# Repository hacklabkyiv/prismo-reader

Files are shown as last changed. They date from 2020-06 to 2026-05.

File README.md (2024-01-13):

# PRISMO readers
# (WIP)

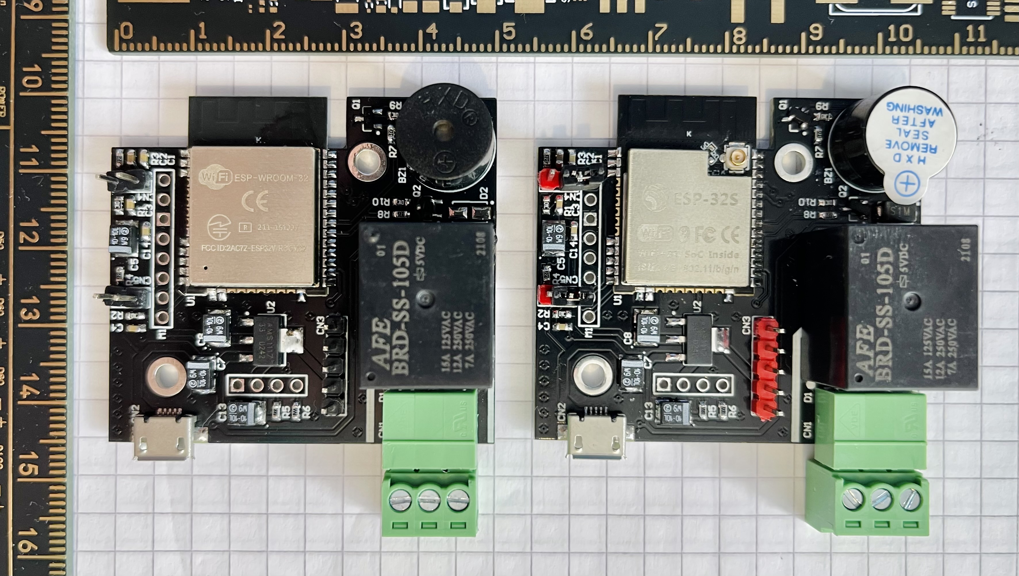
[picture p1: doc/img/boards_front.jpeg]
Boards


[Protocol description](./doc/protocol.md)

## Flashing instructions

Before any development mode interactions with the board it needs to be connected to a computer.
The interface intended for flashing and debugging is UART. Please connect your USB-UART adapter to the pins on the board as shown on the image below:

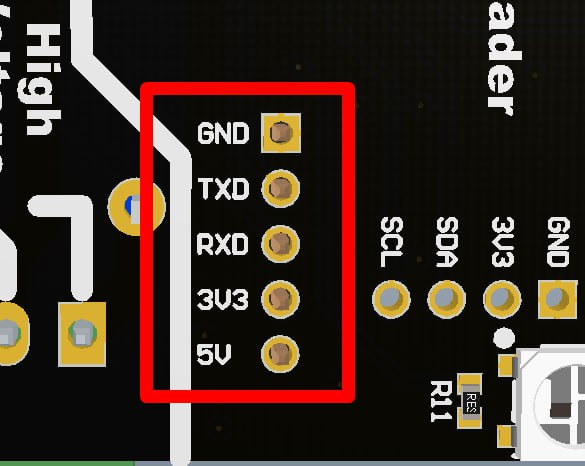
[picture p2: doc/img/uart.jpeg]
uart

```
READER  USB-UART
5V  ->  5V
GND ->  GND
RX  ->  TX
TX  ->  RX
optional
3V3 ->  3V3
```

First of all the information about Micropython and it's installation can be found on their official page: [https://micropython.org/download/esp32/](https://micropython.org/download/esp32/)

Depending on your prefered OS the USB-UART can be named differently.
For example:
 - MacOS `/dev/tty.usbserial-1220`
 - Ubuntu `/dev//dev/ttyUSB0`
 - Windows `COM1`

To enter to the flashing mode the board should start with BOOT0 pin pulled to GND.
In order to achieve that short and hold BOOT pins, then short and release ENABLE pins and then release BOOT pins.

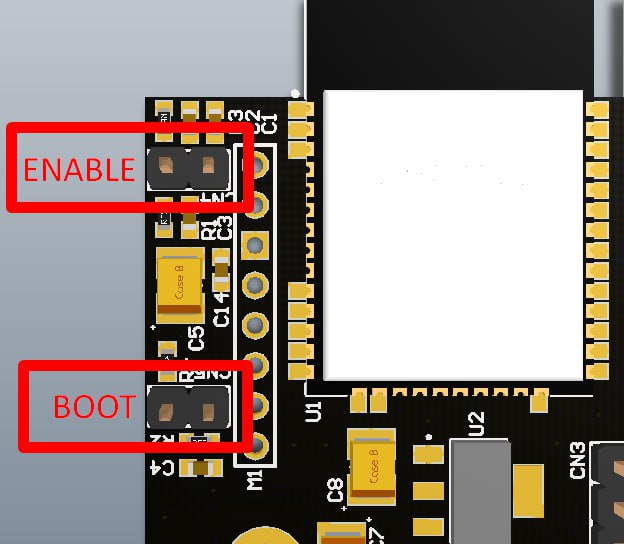
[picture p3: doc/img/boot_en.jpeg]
Boot


The commands also available below:
```sh
esptool.py --chip esp32 --port /dev/tty.usbserial-1220 erase_flash
```

```sh
esptool.py --chip esp32 --port /dev/tty.usbserial-1220 --baud 460800 write_flash -z 0x1000 esp32-20230426-v1.20.0.bin
```

To put source code files on board (ampy)[https://pypi.org/project/adafruit-ampy/] tool is needed.
Put all files from `src` folder to the board one by one.
> It is better for the main.py to be the last one.
>
> main.py starts processes which may affect further access to the board by `ampy` tool
> If that has happened - please enter to the REPL (`picocom` is a nice tool for that) mode and remove `main.py` manually.
> Use this prompt: `import os; os.remove('main.py')`. Don't forget to put `main.py` back in order to be back to normal operation.

```sh
ampy -p /dev/tty.usbserial-11210 -b115200 -d4 put boot.py
ampy -p /dev/tty.usbserial-11210 -b115200 -d4 put PN532.py
ampy -p /dev/tty.usbserial-11210 -b115200 -d4 put config.py
ampy -p /dev/tty.usbserial-11210 -b115200 -d4 put main.py
```
-----------
### HW test

After flashing your device, you can test your hardware. To do this, uncomment `HW_TEST` in `settings.h` file and flash this firmware. In serial monitor, with key is near the RFID frame (baudrate 9600) you should get something like this:

```
------ HW TEST STARTED --------
17:38:34.011 -> ------ HW TEST STARTED --------
17:38:37.001 -> 33384541313932323930304532333845413139323239303045323338454131393232393030453233384541313932323930304532333845413139323239303045323338454131393232393030453233384541
17:38:40.620 -> ------ HW TEST STARTED --------
17:38:43.608 -> ------ HW TEST STARTED --------

```

### Connection test with test server

Comment back `HW_TEST` in `settings.h` and specify network settings there.

```
STASSID	- name of your wifi network
STAPSK 	- password to your wifi network
HOST 	- IP address to your test server.
PORT	- Unique port of your reader
```

In `test_server.py` choose right `MY_IP` - IP of machine where `test_server.py` running and `READER_PORT`.

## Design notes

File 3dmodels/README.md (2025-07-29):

# STL and F3d models for printing the shells for indoor and outdoor use

# for indoor use

***internal_reader_shell_v3*** - main model for indoor euipment readers, can be printed from any plastic  
***logout_button*** - button extension small part  
***transparent_insert*** - installed inside the main model, printed from any kind of transparent filament  
***reader_pcb_spacer*** - 14mm spacers installed between the reader pcb and pn532 rfid scanner board  

***reader_internal_for_plasterboard*** - special model for the door reader to be installed inside a wall behind a 10mm plasterboard so the keys are scanned through the wall  

# for outdoor use 

***outside_sensor_holder_cnc*** - a piece for installing pn532 board. designed to be filled with epoxy and used outdoors. better to be milled from non-metals so they do not interfere with the rfid scanning  
***outside_sensor_holder_cnc_insert*** - 3d printed piece to better hold the pn532 inside the casing  
***outside_sensor_holder_print*** - 3d printed part for pn532 installation. designed to be filled with epoxy. better print from UV-resistant filaments such as ASA or PC  
***outside_sensor_holder_print_screw_plug*** - 3d printed plugs to cover the screws attaching the outdoor part to what it is mounted on  

***sensor_outside_reader_inside_horizontal*** - a box to hold the reader pcb to be mounted inside the room and connected to pn532 via wires. horizontal orientation to be mounted on the door close to the lock mechanism  
***sensor_outside_reader_inside_vertical*** - same but vertical orientation. better suited to be mounted on narrow door frames  

# editable 3d models 

three *.f3d Fusion 360 files that contain all mentioned models for modifications

Have fun!

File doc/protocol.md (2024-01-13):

Communication protocol

{
    "type": "request",
    "id": "BigMill",
    "key": "123534"
}

"type" field can be:
 - "request": ask from reader to server
 - "response": response from server
 - "heartbeat": keepalive heatbeat from reader to server.

"id": identifier of device. It is name of reader, which is usually is the same as the name of machine it is installed, or "server".

{
    "type": "request",
    "operation": "unlock",
    "id": "BigMill",
    "key": "123534"
}

{
    "type": "response",
    "result": "grant"
}

'result' variants
    'grant'
    'deny'
    'usernotfound'

{
    "type": "heartbeat",
    "id": "BigMill"
}

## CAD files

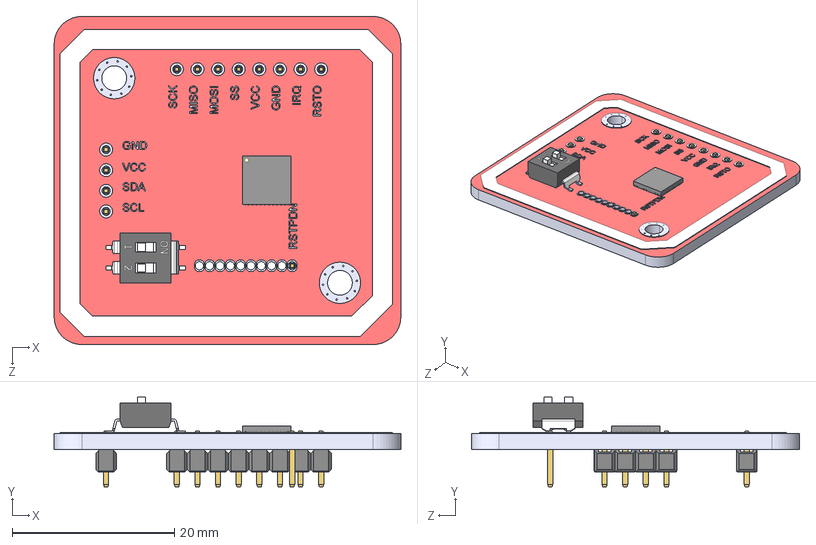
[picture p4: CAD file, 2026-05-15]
hw/rev.3.0/misc/PN532_NFC_Assembly.STEP
42.7 x 11.0 x 40.4 mm
NFC_MODULE_1
Pin Stand 2.54mm_1 x 12
QFN40 (6x6)_1
Switch_2_1
pin_my_1 x 13

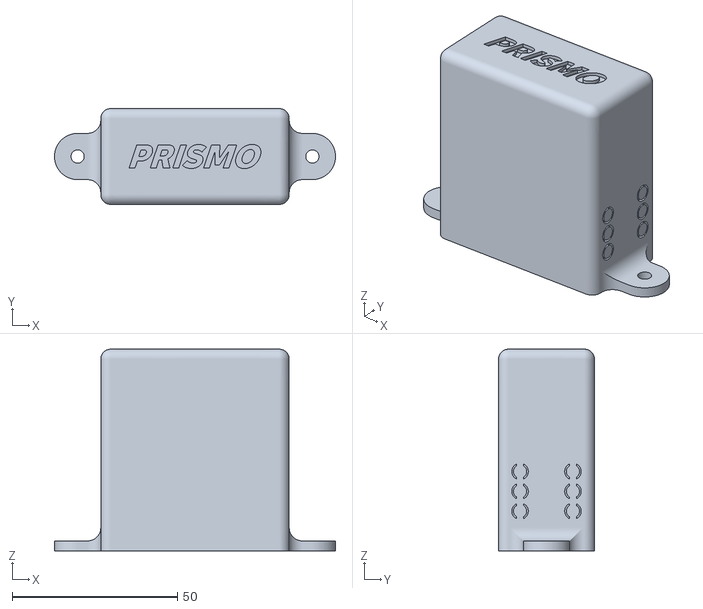
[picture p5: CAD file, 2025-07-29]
3dmodels/scanner_outside_reader_inside_vertical.stl
85.0 x 29.0 x 61.0

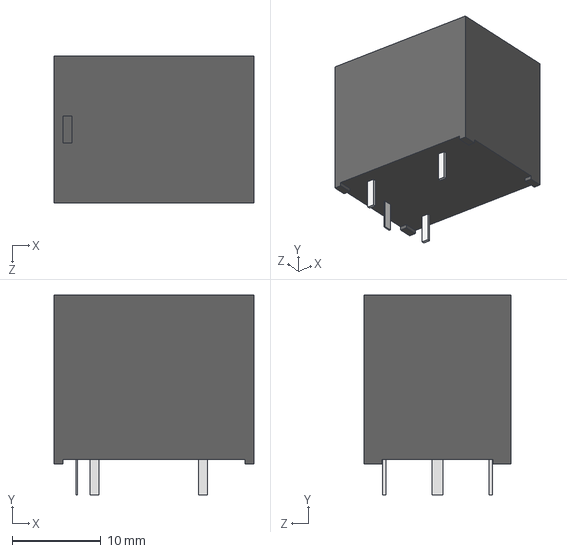
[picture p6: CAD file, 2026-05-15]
hw/rev.3.0/misc/G5LE_1A4.step
22.5 x 22.5 x 16.5 mm

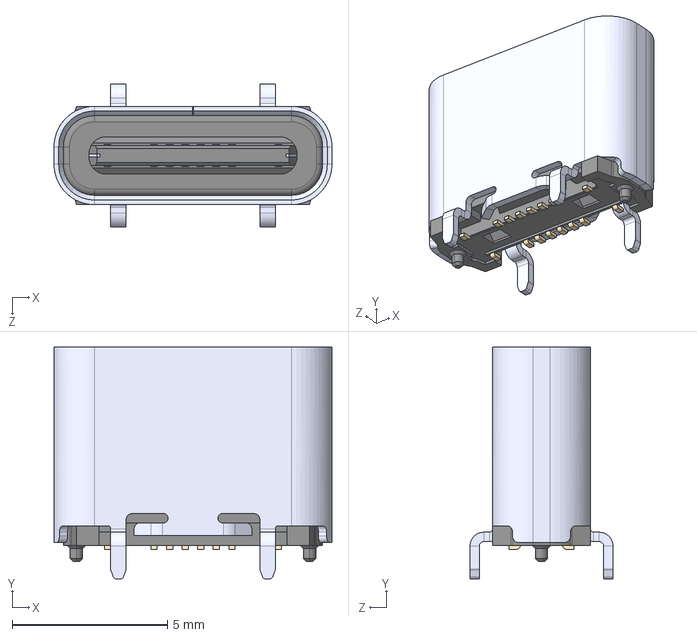
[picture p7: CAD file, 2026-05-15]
hw/rev.3.0/usb_connector/USB4120-03-C_REVA.step
8.94 x 7.45 x 4.60 mm

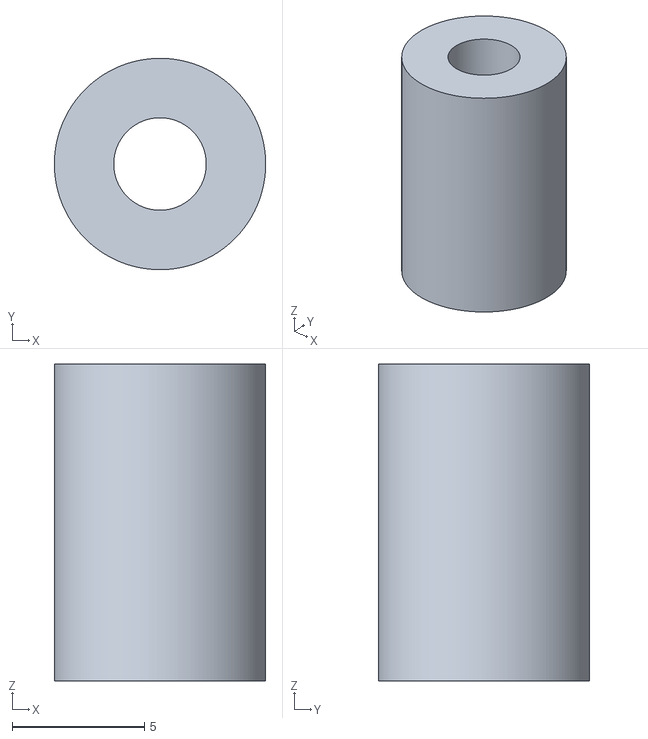
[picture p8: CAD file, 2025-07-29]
3dmodels/reader_pcb_spacer.stl
8.00 x 8.00 x 12.0

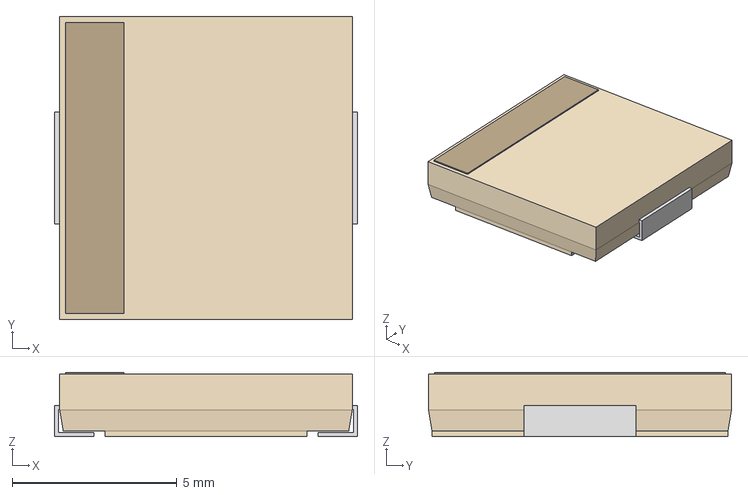
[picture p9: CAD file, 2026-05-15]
hw/rev.3.0/misc/PKMCS0909E4000-R1_MUR.step
9.19 x 9.19 x 1.96 mm

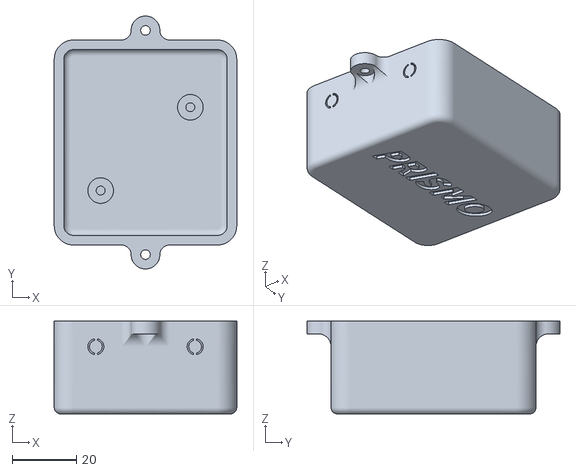
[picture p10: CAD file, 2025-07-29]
3dmodels/scanner_outside_reader_inside_horizontal.stl
57.0 x 79.0 x 29.0

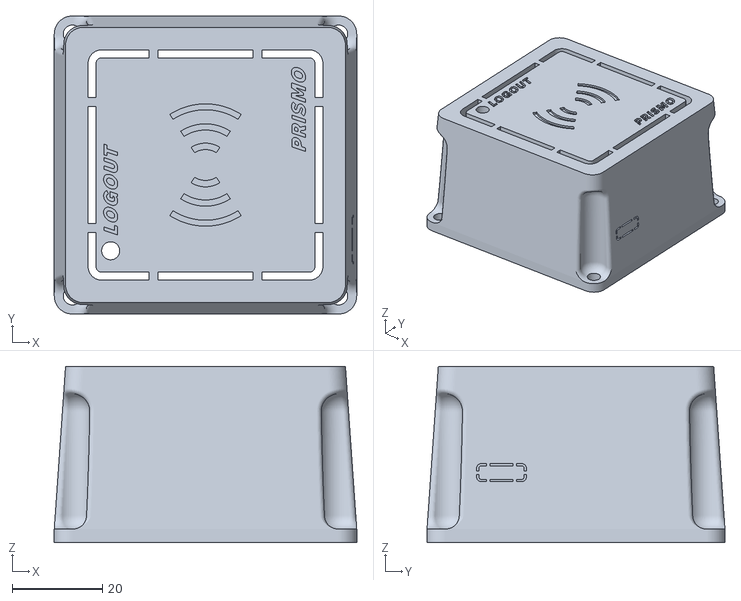
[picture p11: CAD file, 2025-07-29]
3dmodels/internal_reader_shell_v3.stl
67.0 x 66.0 x 39.0

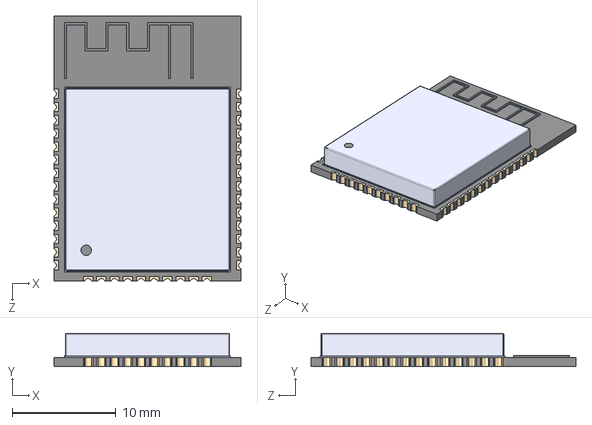
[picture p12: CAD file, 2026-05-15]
hw/rev.3.0/misc/ESP32-WROOM-32.step
18.0 x 3.20 x 25.5 mm

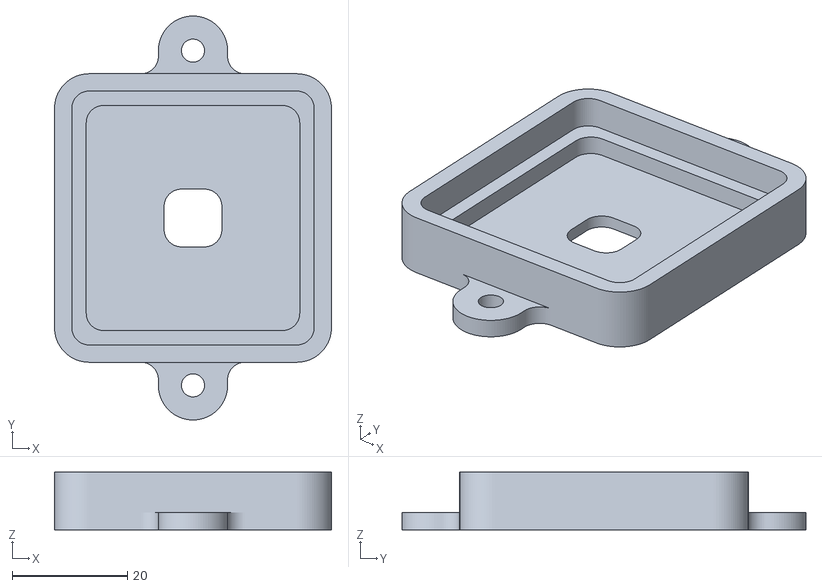
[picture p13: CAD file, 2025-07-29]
3dmodels/outside_sensor_holder_cnc.stl
48.0 x 70.0 x 10.0

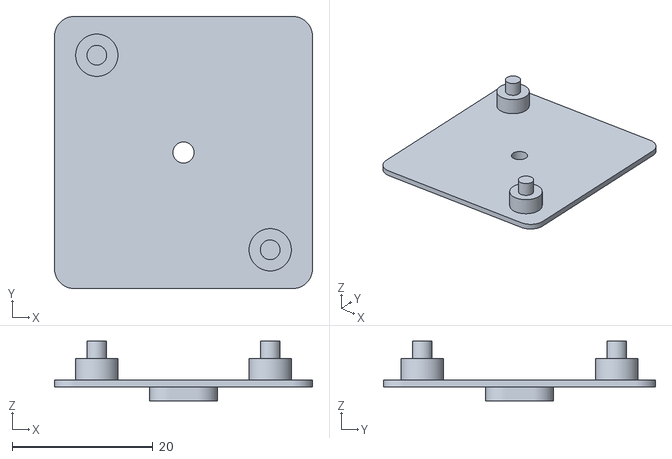
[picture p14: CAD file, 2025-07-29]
3dmodels/outside_sensor_holder_cnc_insert.stl
36.6 x 38.6 x 8.50

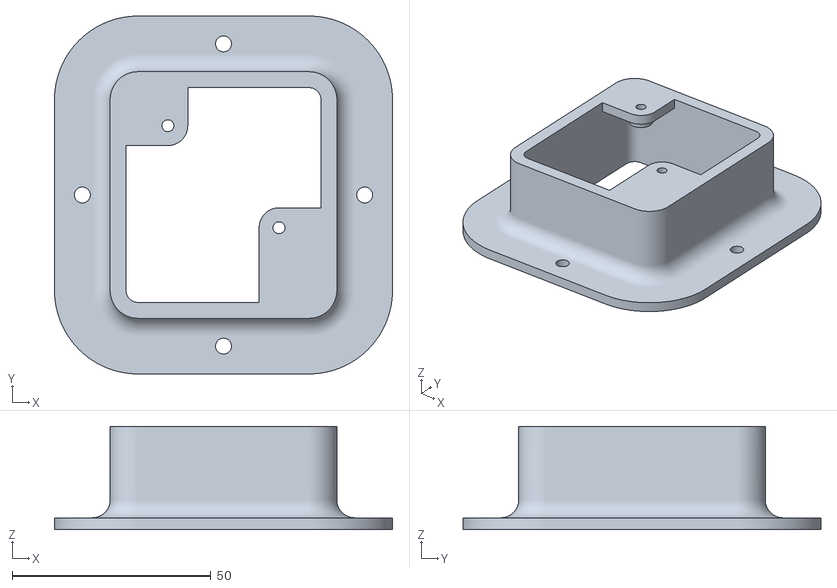
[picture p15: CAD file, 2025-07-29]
3dmodels/Reader_internal_for_plasterboard.stl
85.0 x 90.0 x 26.0

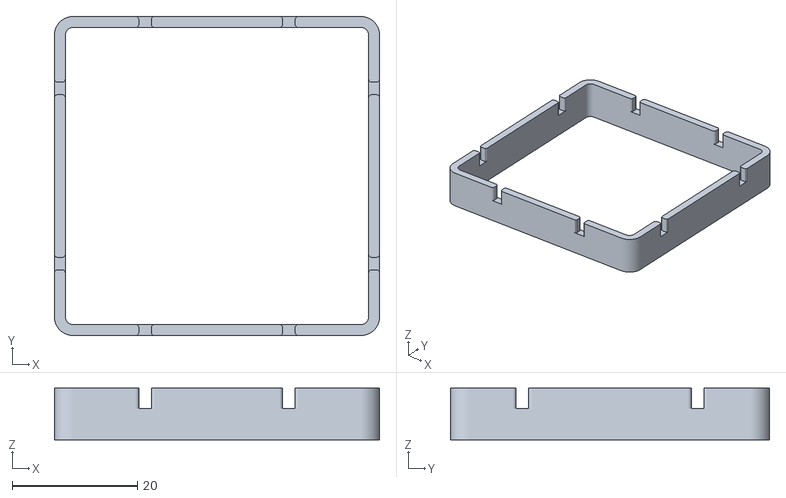
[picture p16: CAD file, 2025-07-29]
3dmodels/transparent_insert.stl
52.0 x 51.0 x 8.25

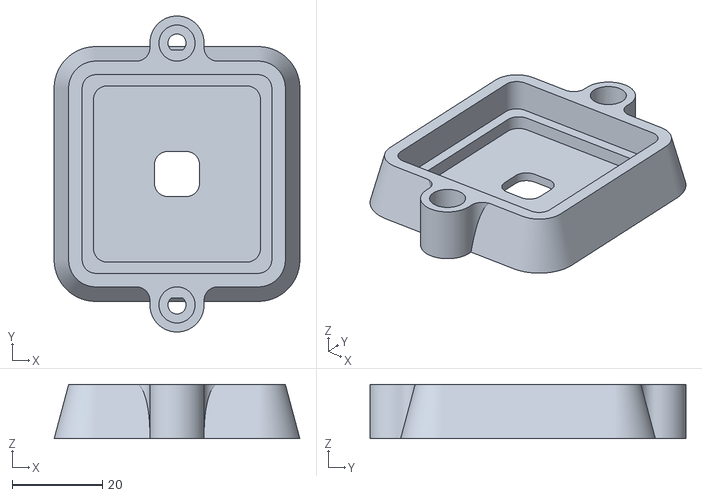
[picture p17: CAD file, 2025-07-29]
3dmodels/outside_sensor_holder_print.stl
54.4 x 70.0 x 12.0

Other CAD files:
3dmodels/logout_button.stl
3dmodels/outside_sensor_holder_print_screw_plug.stl
3dmodels/Reader_internal_plasterboard.f3d
3dmodels/Reader_shell_v3.f3d
3dmodels/reader_scanner_case_v3.f3d

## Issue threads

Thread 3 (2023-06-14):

Decentralize reader's database

Sashkoiv, 2023-06-14:
Currently, all requests from the reader go to the central node which is Raspberry Pi. Then the Raspberry Pi does the magic and replies with whether to unlock the equipment (switch the relay). In this scenario good connection as well as central node stability is vital.

The suggestion is to store a database of allowed users on the reader directly. This should provide more stability and reliability and at the same time untie the reader from infrastructure.

In order to maintain the local reader's database up to date I'd suggest together with the heartbeat packet sending the status of the main database (hash-sum, last update timestamp, request of update, TBD).

By the database, I mean serialized data stored as a file. Most likely the format to be YAML or maybe JSON (which suits best for micropython). In that way after reading the file a dict is created and search in dict works fast enough when in the same time takes not that much of ESP32 resources.

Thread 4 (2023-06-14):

Add a temperature sensor to enable microclimate monitoring

Sashkoiv, 2023-06-14:
Having quick access to the air temperature near the dedicated equipment is a nice feature, especially on winter.
Besides fun diagrams, this will enable the possibility to check whether it is too cold or too hot to go to work in a certain room today. Also, temperature data monitoring can show us a general image of energy resource usage and create a plan to make the organization more ~~cost effective~~ environmentally friendly.

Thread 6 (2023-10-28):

Make reader accessable without connection to wifi and server

leechwort, 2023-10-28:
Currently, there are two problems with autonomous work of reader:
- work without access to server: too long timeout when doing requests. Looks like urequests library does not have timeout feature, so maybe we need some "ping" process to check if server is ok.
- work without wifi. The same thing - need to ping wifi periodically.

leechwort, 2023-10-28:
https://github.com/coffee-it/uPing

Closed 2024-02-04.

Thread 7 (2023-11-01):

IO2 Conflicted with Chip select

leechwort, 2023-11-01:
GPIO2 is used to select one of boot modes, need to choose another one.

leechwort, 2023-12-13:
CS moved to GPIO9, also logout button was connected to GPIO22(instead of i2c communication)

Closed 2024-02-04.

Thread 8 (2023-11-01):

Flash reader with type-C usb only, without any additional USB-UART converters

leechwort, 2023-11-01:
We can use newest ESP32 board with internal USB, capable of device flashing. So we do not need even usb-uart converter.

Closed 2024-02-04.

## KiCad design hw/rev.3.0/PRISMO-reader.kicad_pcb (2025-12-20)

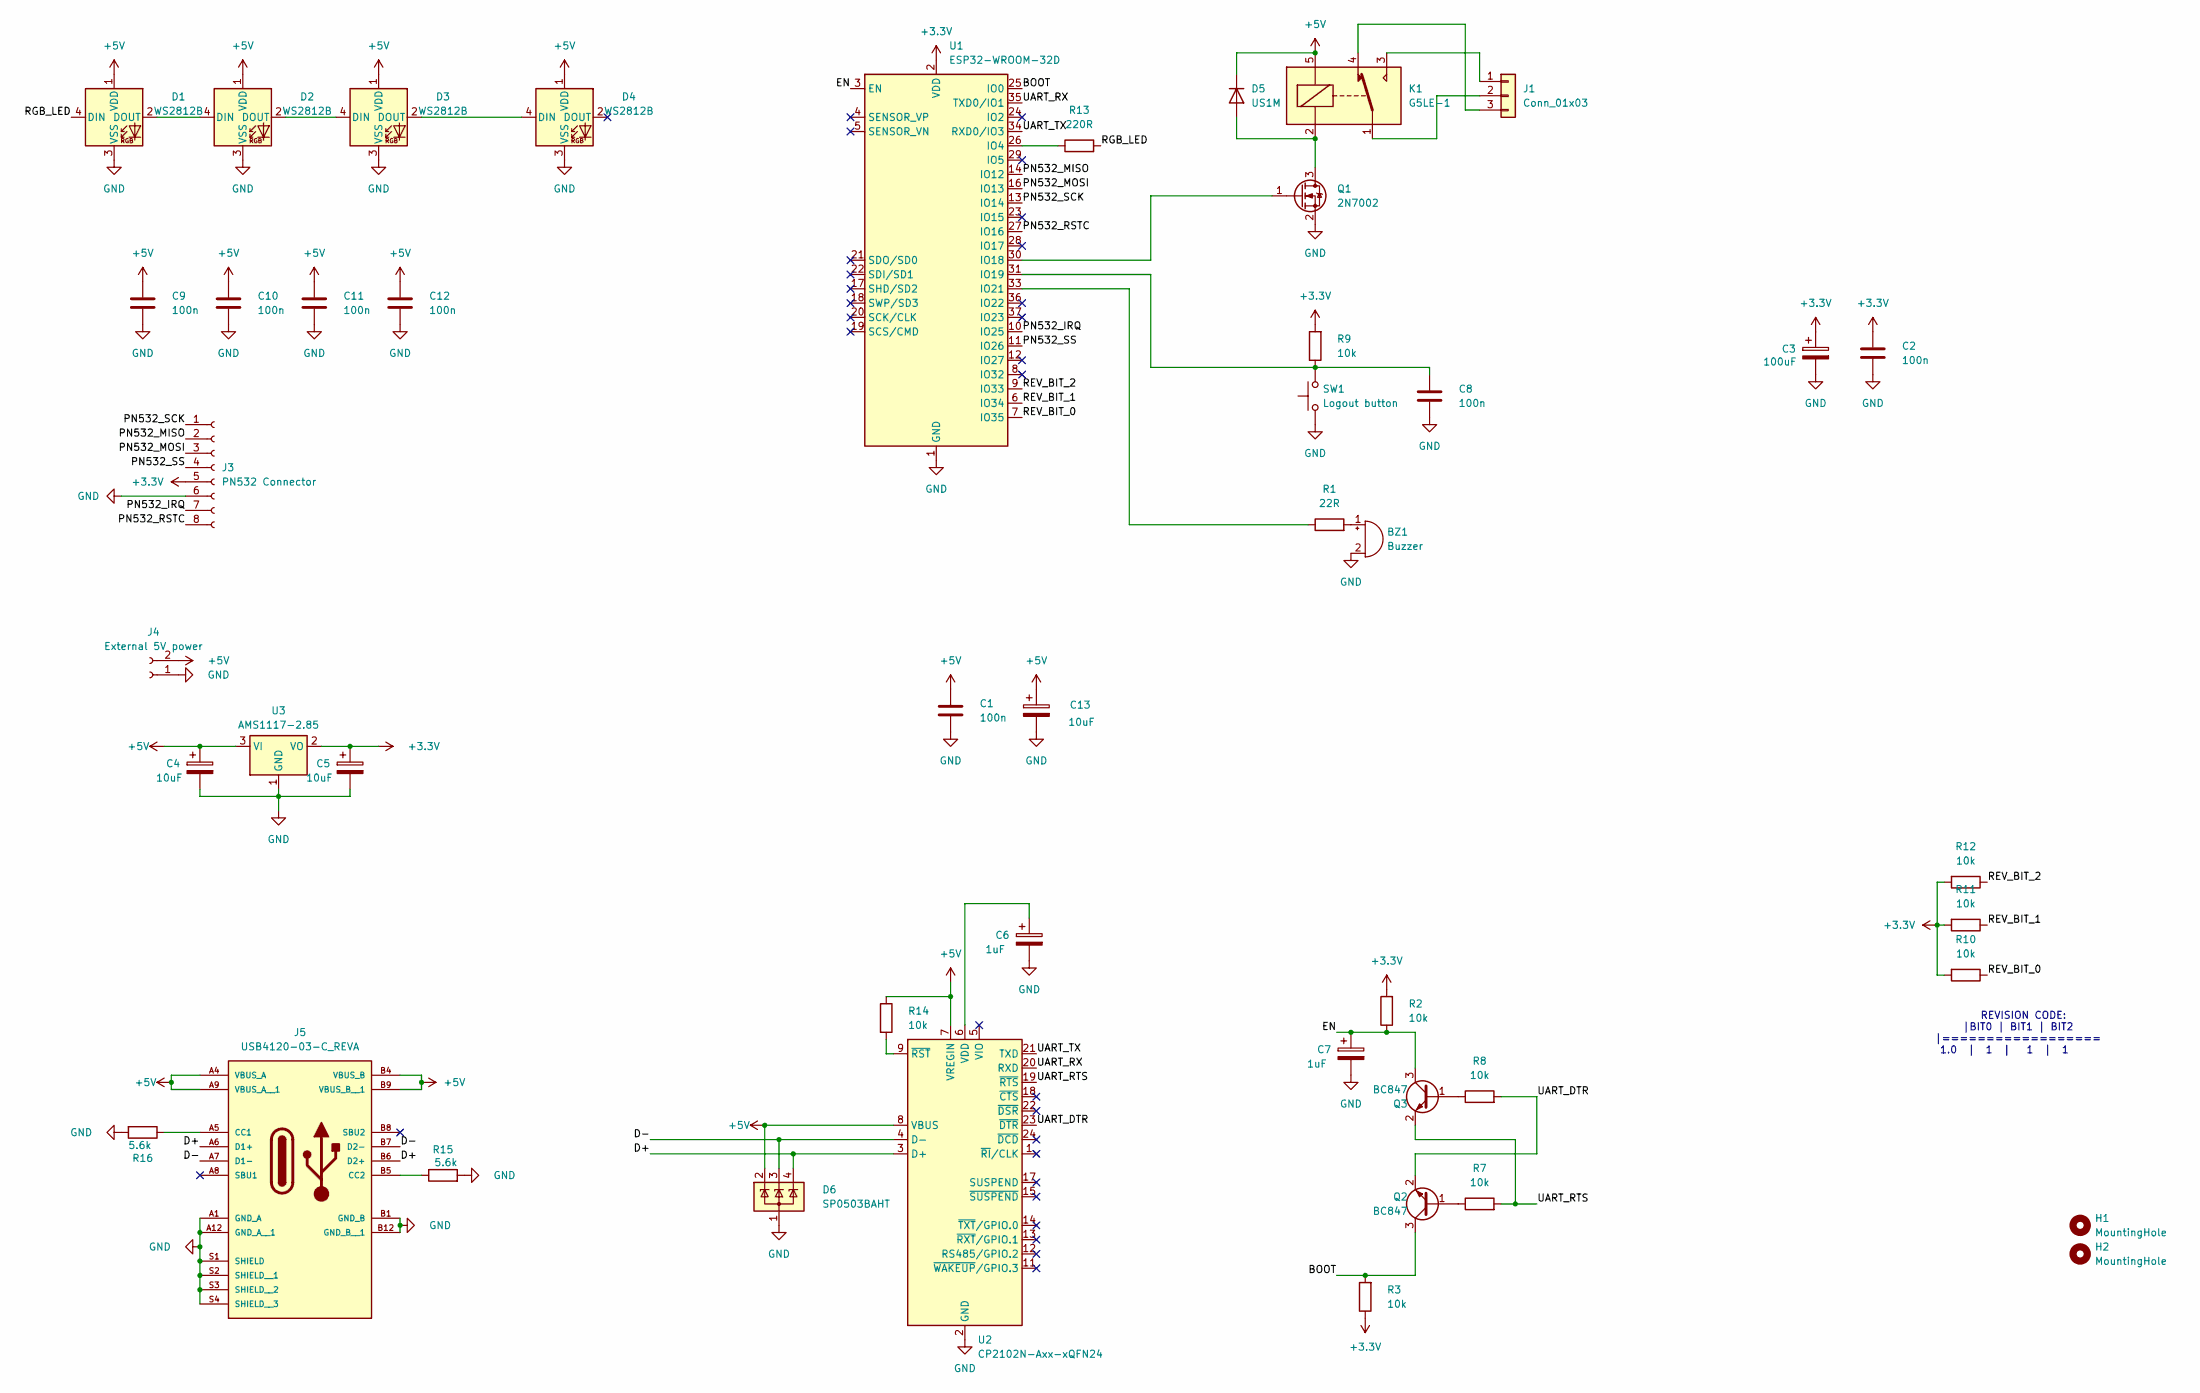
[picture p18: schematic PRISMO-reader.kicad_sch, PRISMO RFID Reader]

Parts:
BZ1: Buzzer; Buzzer_Murata_PKMCS0909E
C1, C2, C8, C9, C10, C11, C12: 100n; C_0805_2012Metric_Pad1.18x1.45mm_HandSolder
C3: 100uF; CP_EIA-3528-21_Kemet-B_Pad1.50x2.35mm_HandSolder
C4, C5, C13: 10uF; CP_EIA-3216-18_Kemet-A_Pad1.58x1.35mm_HandSolder
C6, C7: 1uF; C_0805_2012Metric_Pad1.18x1.45mm_HandSolder
D1, D2, D3, D4: WS2812B; LED_WS2812B_PLCC4_5.0x5.0mm_P3.2mm
D5: US1M; D_SMA
D6: SP0503BAHT; SOT-143
H1, H2: MountingHole; MountingHole_3.5mm
J1: Conn_01x03; TerminalBlock_Phoenix_PT-1,5-3-3.5-H_1x03_P3.50mm_Horizontal
J3: PN532 Connector; PinSocket_1x08_P2.54mm_Vertical_SMD_Pin1Left
J4: External 5V power; JST_XH_B2B-XH-A_1x02_P2.50mm_Vertical
J5: USB4120-03-C_REVA; GCT_USB4120-03-C_REVA
K1: G5LE-1; Relay_SPDT_Omron-G5LE-1
Q1: 2N7002; SOT-23
Q2, Q3: BC847; SOT-23
R1: 22R; R_0805_2012Metric_Pad1.20x1.40mm_HandSolder
R2, R3, R7, R8, R9, R10, R11, R12, R14: 10k; R_0805_2012Metric_Pad1.20x1.40mm_HandSolder
R13: 220R; R_0805_2012Metric_Pad1.20x1.40mm_HandSolder
R15, R16: 5.6k; R_0805_2012Metric_Pad1.20x1.40mm_HandSolder
SW1: Logout button; SW_SPST_PTS645
U1: ESP32-WROOM-32D
U2: CP2102N-Axx-xQFN24; QFN-24-1EP_4x4mm_P0.5mm_EP2.6x2.6mm
U3: AMS1117-2.85; SOT-223-3_TabPin2

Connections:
+3.3V: C2.1, C3.1, C5.1, J3.5, R2.2, R3.1, R9.2, R10.2, R11.2, R12.2, U1.2 (VDD), U3.2 (VO)
+5V: C1.1, C4.1, C9.1, C10.1, C11.1, C12.1, C13.1, D1.1 (VDD), D2.1 (VDD), D3.1 (VDD), D4.1 (VDD), D5.1 (K), D6.2 (K), J4.2, J5.A4 (VBUS_A), J5.A9 (VBUS_A__1), J5.B4 (VBUS_B), J5.B9 (VBUS_B__1), K1.5, R14.1, U2.7 (VREGIN), U2.8 (VBUS), U3.3 (VI)
/BOOT: Q2.3 (C), R3.2, U1.25 (IO0)
/D+: D6.4 (K), J5.A6 (D1+), J5.B6 (D2+), U2.3 (D+)
/D-: D6.3 (K), J5.A7 (D1-), J5.B7 (D2-), U2.4 (D-)
/EN: C7.1, Q3.3 (C), R2.1, U1.3 (EN)
/PN532_IRQ: J3.7, U1.10 (IO25)
/PN532_MISO: J3.2, U1.14 (IO12)
/PN532_MOSI: J3.3, U1.16 (IO13)
/PN532_RSTC: J3.8, U1.27 (IO16)
/PN532_SCK: J3.1, U1.13 (IO14)
/PN532_SS: J3.4, U1.11 (IO26)
/REV_BIT_0: R10.1, U1.7 (IO35)
/REV_BIT_1: R11.1, U1.6 (IO34)
/REV_BIT_2: R12.1, U1.9 (IO33)
/RGB_LED: D1.4 (DIN), R13.2
/UART_DTR: Q2.2 (E), R8.2, U2.23 (~DTR)
/UART_RTS: Q3.2 (E), R7.2, U2.19 (~RTS)
/UART_RX: U1.35 (TXD0/IO1), U2.20 (RXD)
/UART_TX: U1.34 (RXD0/IO3), U2.21 (TXD)
GND: BZ1.2 (+), C1.2, C2.2, C3.2, C4.2, C5.2, C6.2, C7.2, C8.2, C9.2, C10.2, C11.2, C12.2, C13.2, D1.3 (VSS), D2.3 (VSS), D3.3 (VSS), D4.3 (VSS), D6.1 (A), J3.6, J4.1, J5.A1 (GND_A), J5.A12 (GND_A__1), J5.B1 (GND_B), J5.B12 (GND_B__1), J5.S1 (SHIELD), J5.S2 (SHIELD__1), J5.S3 (SHIELD__2), J5.S4 (SHIELD__3), Q1.2 (S), R15.2, R16.2, SW1.1, U1.1 (GND), U1.15 (GND), U1.38 (GND), U1.39 (GND), U2.2 (GND), U2.25 (GND), U3.1 (GND)
unnamed: BZ1.1 (-), R1.2
unnamed: D1.2 (DOUT), D2.4 (DIN)
unnamed: D2.2 (DOUT), D3.4 (DIN)
unnamed: D3.2 (DOUT), D4.4 (DIN)
unnamed: D5.2 (A), K1.2, Q1.3 (D)
unnamed: J1.1, K1.3
unnamed: J1.2, K1.1
unnamed: J1.3, K1.4
unnamed: J5.A5 (CC1), R16.1
unnamed: J5.B5 (CC2), R15.1
unnamed: Q1.1 (G), U1.30 (IO18)
unnamed: Q2.1 (B), R7.1
unnamed: Q3.1 (B), R8.1
unnamed: R13.1, U1.26 (IO4)
unnamed: C8.1, R9.1, SW1.2, U1.31 (IO19)
unnamed: R1.1, U1.33 (IO21)
unnamed: C6.1, U2.6 (VDD)
unnamed: R14.2, U2.9 (~RST)

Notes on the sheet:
REVISION CODE: |BIT0 | BIT1 | BIT2 |================== 1.0 | 1 | 1 | 1

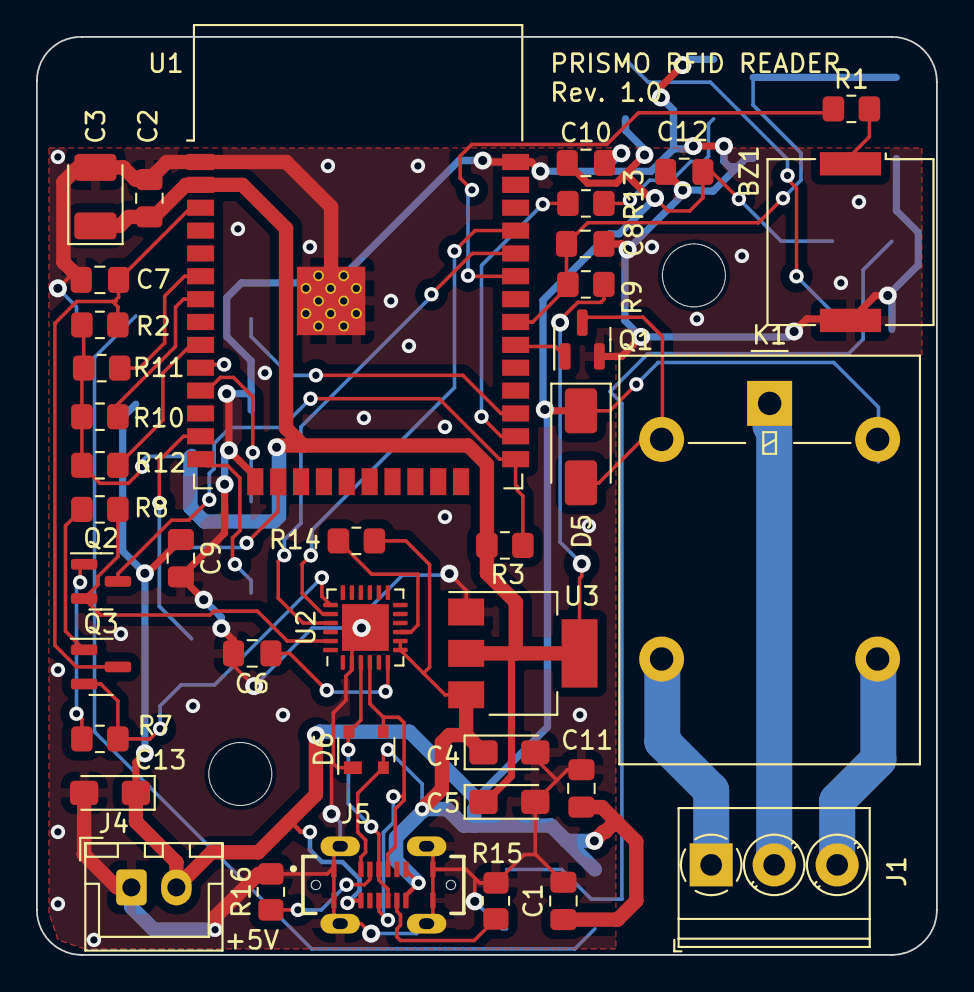
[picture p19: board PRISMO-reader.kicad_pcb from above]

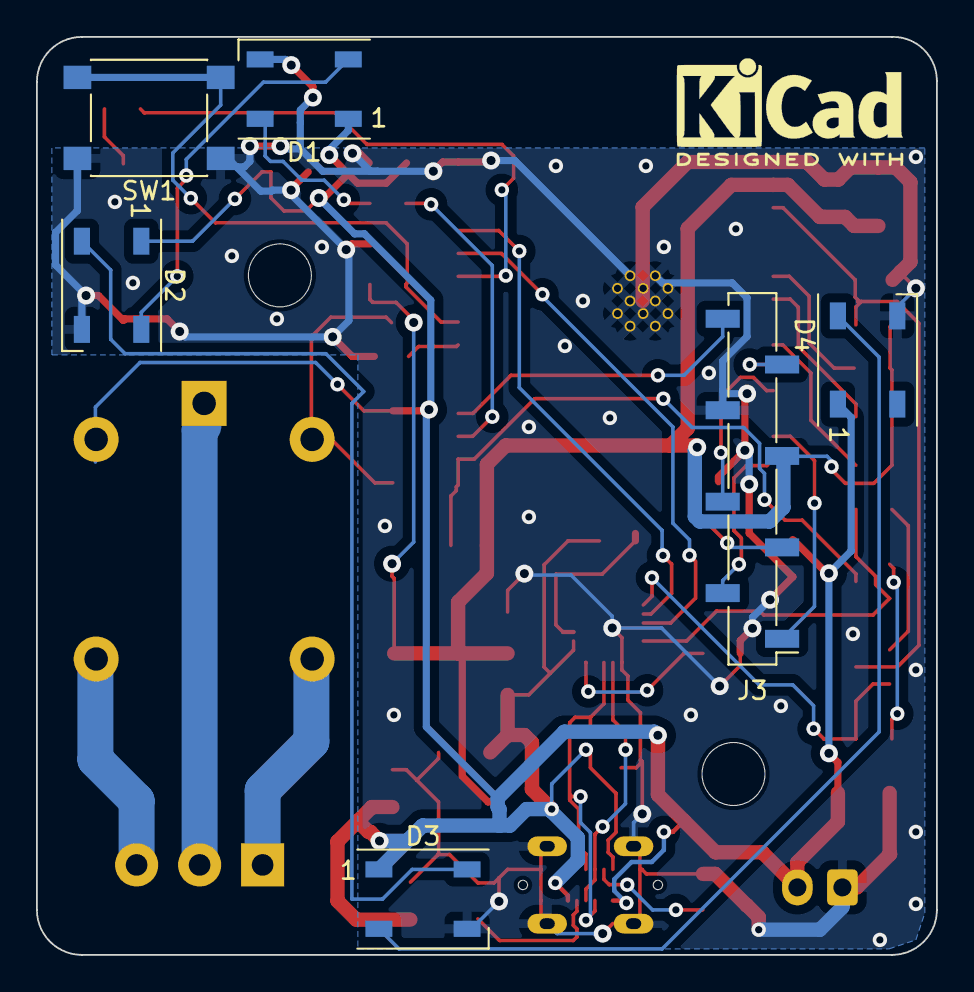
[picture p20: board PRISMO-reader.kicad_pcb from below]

Board: 2 copper layers, 50.0 x 51.0 mm, 47 parts (6 on the bottom side), 39 nets.

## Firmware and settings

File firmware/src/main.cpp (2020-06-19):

#include <Arduino.h>
#include <ESP8266WiFi.h>
#include <ArduinoJson.h>
#include "rdm6300.h"
#include "settings.h"
#include "misc.h"

int rx_mux_pin = 12;
int relay_pin = 13;
int led_blue_pin = 4;
int led_red_pin = 5;
int buzzer_pin = 2;

unsigned long heartbeat_last_time = millis();

Rdm6300 rdm6300;
WiFiClient client;
DynamicJsonDocument packet(1024);

const char* host = HOST;
const uint16_t port = PORT;

void setup()
{
  pinMode(led_blue_pin, OUTPUT);
  pinMode(led_red_pin, OUTPUT);
  pinMode(buzzer_pin, OUTPUT);
  pinMode(rx_mux_pin, OUTPUT);
  pinMode(relay_pin, OUTPUT);
  digitalWrite(buzzer_pin, LOW);
  digitalWrite(led_red_pin, HIGH);
  // Mux UART RX to RDM6300 
  digitalWrite(rx_mux_pin, HIGH);
  Serial.begin(9600);
  rdm6300.begin(&Serial);
  Serial.println("Start initialization");
}

void denyBeep()
{
  digitalWrite(buzzer_pin, HIGH);
  delay(50);
  digitalWrite(buzzer_pin, LOW);
  delay(100);
  digitalWrite(buzzer_pin, HIGH);
  delay(50);
  digitalWrite(buzzer_pin, LOW);
}

void allowBeep()
{
  digitalWrite(buzzer_pin, HIGH);
  delay(50);
  digitalWrite(buzzer_pin, LOW);
}

void userNotFoundBeep()
{
  for (int i = 0; i < 3; i++)
  {
    digitalWrite(buzzer_pin, HIGH);
    delay(50);
    digitalWrite(buzzer_pin, LOW);
  }
}

void wifiConnect()
{
  Serial.print("Connecting to ");
  Serial.println(STASSID);

  /* Explicitly set the ESP8266 to be a WiFi-client, otherwise, it by default,
     would try to act as both a client and an access-point and could cause
     network-issues with your other WiFi-devices on your WiFi-network. */
  WiFi.mode(WIFI_STA);
  WiFi.hostname(HOSTNAME);
  WiFi.begin(STASSID, STAPSK);
  Serial.println("=============================");
  Serial.println("Connecting to WiFi");
  while (WiFi.status() != WL_CONNECTED) {
    delay(500);
    Serial.print(".");
  }

  Serial.println("");
  Serial.println("WiFi connected!");
  Serial.println("IP address: ");
  Serial.println(WiFi.localIP());
  Serial.println("=============================");
}

void connectToServer()
{
  Serial.print("connecting to ");
  Serial.print(host);
  Serial.print(':');
  Serial.println(port);
  while (!client.connect(host, port)) {
    Serial.println("connection failed, try again");
    delay(1000);
  }
  //client.keepAlive(100, 10, 6);
  Serial.println("Connection successful!");
}

// TODO implement normal hash function, for example Adler32
String hashTag(uint32_t tag)
{
  char buf[7];
  // Encoded with secret patented Hacklab technology:)
  uint32_t sercret_code = (tag) ^ 0xFFFFFF ^ 0xC78DC7;
  sprintf(buf, "%02X%02X%02X",
        (uint8_t) ~((sercret_code >> 16) & 0xFF),
        (uint8_t) ~((sercret_code >> 8) & 0xFF),
        (uint8_t) ~( sercret_code  & 0xFF)
        );
  return String(buf);
}

int checkAccess(uint32_t tagId)
{
  String requestPrefix = "TAG:";
  String hashedTagValue = hashTag(tagId);
  StaticJsonDocument<200> doc;
  //client.println(requestPrefix + hashedTagValue);
  packet["type"] = "request";
  packet["operation"] = "unlock";
  packet["id"] = MACHINE_NAME;
  packet["key"] = hashedTagValue;
  Serial.print(F("Sending request..."));
  serializeJson(packet, client);
  client.write("\r\n");
  Serial.println(">>>> Request sent, hashed value is: " + hashedTagValue);
  String answer = client.readStringUntil('\n');
  Serial.println(">>>> Received from server: " + answer);
  DeserializationError error = deserializeJson(doc, answer);
  if (error) {
    Serial.print(F("deserializeJson() failed: "));
    Serial.println(error.c_str());
    return UNKNOWN_ERROR;
  }
  if (doc["result"] == "grant")
    return ACCESS_GRANTED;
  else if (doc["result"] == "deny")
    return ACCESS_DENIED;
  else if (doc["result"] == "norecord")
    return USER_NOT_FOUND;
}

int logoutUser(uint32_t tagId)
{
  String requestPrefix = "TAG:";
  String hashedTagValue = hashTag(tagId);
  StaticJsonDocument<200> doc;
  //client.println(requestPrefix + hashedTagValue);
  packet["type"] = "request";
  packet["operation"] = "lock";
  packet["id"] = MACHINE_NAME;
  packet["key"] = hashedTagValue;
  Serial.print(F("Sending request..."));
  serializeJson(packet, client);
  client.write("\r\n");
  Serial.println(">>>> Request sent, hashed value is: " + hashedTagValue);
  String answer = client.readStringUntil('\n');
  Serial.println(">>>> Received from server: " + answer);
  DeserializationError error = deserializeJson(doc, answer);
  if (error) {
    Serial.print(F("deserializeJson() failed: "));
    Serial.println(error.c_str());
    return UNKNOWN_ERROR;
  }
  if (doc["result"] == "confirmed")
    return LOGOUT_CONFIRMED;
}

void sendHeartbeat()
{
  StaticJsonDocument<200> doc;
  //client.println(requestPrefix + hashedTagValue);
  packet["type"] = "heartbeat";
  packet["id"] = MACHINE_NAME;
  Serial.print(F("Sending heartbeat..."));
  serializeJson(packet, client);
  client.write("\r\n");
  heartbeat_last_time = millis();
}
void unlockReader()
{
  digitalWrite(relay_pin,HIGH);
  digitalWrite(led_blue_pin, HIGH);
  digitalWrite(led_red_pin, LOW);
}

void lockReader()
{
  digitalWrite(relay_pin,LOW);
  digitalWrite(led_blue_pin, LOW);
  digitalWrite(led_red_pin, HIGH);
}
int state = WIFI_CONNECTION;
int previousState = WIFI_CONNECTION;
bool isUnlocked = false;

#ifdef HW_TEST
void loop()
{
  Serial.println("------ HW TEST STARTED --------");
  // Test LED blinking
  digitalWrite(led_blue_pin, HIGH);
  delay(500);
  digitalWrite(led_blue_pin, LOW);
  delay(500);
  digitalWrite(led_red_pin, HIGH);
  delay(500);
  digitalWrite(led_red_pin, LOW);
  delay(500);
  // Check Relay
  digitalWrite(relay_pin,HIGH);
  delay(500);
  digitalWrite(relay_pin,LOW);
  delay(500);
  // Read raw data from RDM6300 reader
  while (Serial.available() > 0) {    
          int incomingByte = Serial.read();
          Serial.print(incomingByte, HEX);
  }
}

#else
void loop()
{
  switch (state){
  case WAIT_FOR_KEY:
    if (rdm6300.update()) {
      uint32_t tag = rdm6300.get_tag_id();
      Serial.print("Tag received: ");
      Serial.println(tag, HEX);
      int requestResult = checkAccess(tag);
      if (requestResult == ACCESS_GRANTED) {
        Serial.println("Access granted by server!");
        allowBeep();
        unlockReader();
        isUnlocked = true;
        state = WAIT_FOR_LOCK;
        Serial.print("State changed to wait for lock ");
      } else if (requestResult == ACCESS_DENIED){
        Serial.println("Access denied by server!");
        denyBeep();
      } else if (requestResult == USER_NOT_FOUND) {
        // process user not found case
        userNotFoundBeep();
      }
    }
    // Check connection
    if (!client.connected()) {
      Serial.print("Connection with server lost, try to reconnect");
      state = CONNECTING_TO_SERVER;
    } else if ((millis() - heartbeat_last_time) > HEARTBEAT_INTERVAL) {
      sendHeartbeat();
    }
    break;
  case WAIT_FOR_LOCK:
  //Serial.print("Wait for lock request");
    if (rdm6300.update()) {
      uint32_t tag = rdm6300.get_tag_id();
      Serial.print("LOGOUT request");
      int requestResult = logoutUser(tag);
      if (requestResult == LOGOUT_CONFIRMED)
      {
        client.println("LOGOUT OK");
        lockReader();
        allowBeep();
        isUnlocked = false;
        state = WAIT_FOR_KEY;
      }   
    }
    // Check connection
    if (!client.connected()) {
      Serial.print("Connection with server lost, try to reconnect");
      state = CONNECTING_TO_SERVER;
    } else if ((millis() - heartbeat_last_time) > HEARTBEAT_INTERVAL) {
      sendHeartbeat();
    }
    break;
  case CONNECTING_TO_SERVER:
    if (WiFi.status() == WL_CONNECTED) {
      connectToServer();
      if (isUnlocked)
        state = WAIT_FOR_LOCK;
      else
        state = WAIT_FOR_KEY;
      
    } else {
      Serial.println("No WIFI connection, try to reconnect");
      state = WIFI_CONNECTION;
    }
    break;
  case WIFI_CONNECTION:
    wifiConnect();
    state = CONNECTING_TO_SERVER;
    break;
  default:
    break;
  }
}
#endif

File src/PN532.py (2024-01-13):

# @Author: carlosgilgonzalez
# @Date:   2019-10-15T16:13:47+01:00
# @Last modified by:   carlosgilgonzalez
# @Last modified time: 2019-10-15T16:56:27+01:00


# Original work:
# Adafruit PN532 NFC/RFID control library.
# Author: Tony DiCola

# Partial Port to Micropython:
# Micropython PN532 NFC/RFID control library.
# Author: Carlos Gil Gonzalez
"""
Micropython PN532 NFC/RFID control library (SPI)
https://github.com/Carglglz/NFC_PN532_SPI
"""

import time
from machine import Pin
from micropython import const

# __version__ = "0.0.0-auto.0"
# __repo__ = "https://github.com/adafruit/Adafruit_CircuitPython_PN532.git"

# pylint: disable=bad-whitespace
_PREAMBLE = const(0x00)
_STARTCODE1 = const(0x00)
_STARTCODE2 = const(0xFF)
_POSTAMBLE = const(0x00)

_HOSTTOPN532 = const(0xD4)
_PN532TOHOST = const(0xD5)

# PN532 Commands
_COMMAND_DIAGNOSE = const(0x00)
_COMMAND_GETFIRMWAREVERSION = const(0x02)
_COMMAND_GETGENERALSTATUS = const(0x04)
_COMMAND_SETSERIALBAUDRATE = const(0x10)
_COMMAND_SETPARAMETERS = const(0x12)
_COMMAND_SAMCONFIGURATION = const(0x14)

_COMMAND_INLISTPASSIVETARGET = const(0x4A)

_COMMAND_INDATAEXCHANGE = const(0x40)
_COMMAND_INCOMMUNICATETHRU = const(0x42)


_RESPONSE_INDATAEXCHANGE = const(0x41)
_RESPONSE_INLISTPASSIVETARGET = const(0x4B)

_WAKEUP = const(0x55)

_MIFARE_ISO14443A = const(0x00)

# Mifare Commands
MIFARE_CMD_AUTH_A = const(0x60)
MIFARE_CMD_AUTH_B = const(0x61)
MIFARE_CMD_READ = const(0x30)
MIFARE_CMD_WRITE = const(0xA0)
MIFARE_ULTRALIGHT_CMD_WRITE = const(0xA2)

# Known keys
KEY_DEFAULT_B = bytes([0xFF]*6)


_ACK = b'\x00\x00\xFF\x00\xFF\x00'
_FRAME_START = b'\x00\x00\xFF'
# pylint: enable=bad-whitespace
_SPI_STATREAD = const(0x02)
_SPI_DATAWRITE = const(0x01)
_SPI_DATAREAD = const(0x03)
_SPI_READY = const(0x01)


def _reset(pin):
    """Perform a hardware reset toggle"""
    pin.init(Pin.OUT)
    pin.value(True)
    time.sleep(0.1)
    pin.value(False)
    time.sleep(0.5)
    pin.value(True)
    time.sleep(0.1)


class BusyError(Exception):
    """Base class for exceptions in this module."""
    pass


def reverse_bit(num):
    """Turn an LSB byte to an MSB byte, and vice versa. Used for SPI as
    it is LSB for the PN532, but 99% of SPI implementations are MSB only!"""
    result = 0
    for _ in range(8):
        result <<= 1
        result += (num & 1)
        num >>= 1
    return result


class PN532:
    """Driver for the PN532 connected over SPI. Pass in a hardware or bitbang
    SPI device & chip select digitalInOut pin. Optional IRQ pin (not used),
    reset pin and debugging output."""

    def __init__(self, spi, cs_pin, irq=None, reset=None, debug=False):
        """Create an instance of the PN532 class using SPI"""
        self.debug = debug
        self._irq = irq
        self.CSB = cs_pin
        self._spi = spi
        self.CSB.on()
        if reset:
            if debug:
                print("Resetting")
            _reset(reset)

        try:
            self._wakeup()
            # self.get_firmware_version()  # first time often fails, try 2ce
            return
        except (BusyError, RuntimeError):
            pass
        # self.get_firmware_version()

    def _wakeup(self):
        """Send any special commands/data to wake up PN532"""
        time.sleep(1)
        self.CSB.off()
        time.sleep_ms(2)
        self._spi.write(bytearray([0x00]))
        time.sleep_ms(2)
        self.CSB.on()  # pylint: disable=no-member
        time.sleep(1)

    def _wait_ready(self, timeout=1000):
        """Poll PN532 if status byte is ready, up to `timeout` milliseconds"""
        status_query = bytearray([reverse_bit(_SPI_STATREAD), 0])
        status = bytearray([0, 0])
        timestamp = time.ticks_ms()
        while time.ticks_diff(time.ticks_ms(), timestamp) < timeout:
            time.sleep(0.02)   # required
            self.CSB.off()
            time.sleep_ms(2)
            self._spi.write_readinto(status_query, status)
            time.sleep_ms(2)
            self.CSB.on()
            if reverse_bit(status[1]) == 0x01:  # LSB data is read in MSB
                return True      # Not busy anymore!
            else:
                time.sleep(0.01)  # pause a bit till we ask again
        # Timed out!
        return False

    def _read_data(self, count):
        """Read a specified count of bytes from the PN532."""
        # Build a read request frame.
        frame = bytearray(count+1)
        # Add the SPI data read signal byte, but LSB'ify it
        frame[0] = reverse_bit(_SPI_DATAREAD)
        time.sleep(0.02)   # required
        self.CSB.off()
        time.sleep_ms(2)
        self._spi.write_readinto(frame, frame)
        time.sleep_ms(2)
        self.CSB.on()
        for i, val in enumerate(frame):
            frame[i] = reverse_bit(val)  # turn LSB data to MSB
        if self.debug:
            print("DEBUG: _read_data: ", [hex(i) for i in frame[1:]])
        return frame[1:]   # don't return the status byte

    def _write_data(self, framebytes):
        """Write a specified count of bytes to the PN532"""
        # start by making a frame with data write in front,
        # then rest of bytes, and LSBify it
        rev_frame = [reverse_bit(x)
                     for x in bytes([_SPI_DATAWRITE]) + framebytes]
        if self.debug:
            print("DEBUG: _write_data: ", [hex(i) for i in rev_frame])
        time.sleep(0.02)   # required
        self.CSB.off()
        time.sleep_ms(2)
        self._spi.write(bytes(rev_frame))  # pylint: disable=no-member
        time.sleep_ms(2)
        self.CSB.on()

    def _write_frame(self, data):
        """Write a frame to the PN532 with the specified data bytearray."""
        assert data is not None and 1 < len(
            data) < 255, 'Data must be array of 1 to 255 bytes.'
        # Build frame to send as:
        # - Preamble (0x00)
        # - Start code  (0x00, 0xFF)
        # - Command length (1 byte)
        # - Command length checksum
        # - Command bytes
        # - Checksum
        # - Postamble (0x00)
        length = len(data)
        frame = bytearray(length+8)
        frame[0] = _PREAMBLE
        frame[1] = _STARTCODE1
        frame[2] = _STARTCODE2
        checksum = sum(frame[0:3])
        frame[3] = length & 0xFF
        frame[4] = (~length + 1) & 0xFF
        frame[5:-2] = data
        checksum += sum(data)
        frame[-2] = ~checksum & 0xFF
        frame[-1] = _POSTAMBLE
        # Send frame.
        if self.debug:
            print('DEBUG: _write_frame: ', [hex(i) for i in frame])
        self._write_data(bytes(frame))
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

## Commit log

2020-02-14 PCB: Added very first version
    [pcb.kicad_pcb, pcb.sch]
2020-02-28 Some impromevents
    - GPIO15 should be connected to GND
    - Buzzer connected through transistor
    - Buzzer can be disabled with switch(because it enables during flashing, which is annoying)
    - Smaller terminal block for power connector
    [pcb.sch]
2020-02-28 Different optimizations
    [pcb.kicad_pcb, pcb.sch]
2020-05-22 GPIO9 and GPIO10 should be not used, fix this
    we cannot use these pins because they are internally connected to SPI
    flash memory.
    [pcb.kicad_pcb, pcb.sch]
2020-06-05 Firmware: Switch to PlatformIO
2020-06-19 Firmware: Refactor and bug fixes
    [main.cpp]
2023-06-03 Move to ESP32 and Gwiot7941e reader
    [pcb.kicad_pcb, pcb.sch]
2023-06-08 Attach hardware design repo as a submodule
    [pcb.kicad_pcb, pcb.sch]
2023-07-02 Correct pins according to the manufactured board
    [config.py]
2023-07-26 Read on interrupt instead of the timer
    Increase timeout from 500 to 5000 (5sec), due to library for PN532
    specifics.
    Once the read method is called it tries to read every timeout q-ty
    of time.
    In order to make it read on interrupt also the timeout is increased
    to a huge amount of time.
2023-11-01 Trying to allow offline work
    There are still some bug when device hangs or reboots when network
    request failed. Need more QA!
    [config.py]
2023-11-01 Fix bug with reboot and code refactoring
    * Fixed bug with simultaneous reboot after GET request - moved logic
    from IRQ to polling mode
    * Code refactoring
    * Beep control because my cat Cherry asks me to turn off this sound!
    [config.py]
2023-11-02 Add ping before any requests performed
    Inside requests module, sockets are used in blocking mode and current
    implementation of LWIP of ESP32 does not support timeouts. This leads
    to long timeouts when host is unreachable and this blocks work of whole
    reader. As workaround quick ping in polling mode was added before any
    requests are performed.
    [config.py]
2023-12-13 Changed CS pin, logout button and flasher script
2024-01-13 Version 2.0 hardware + KiCad
    [3.stp, CAPC_0603.stp, FSM8JSMA Alcoswitch - detailed.stp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]
2024-01-17 Files updated
    [Reader.kicad_sch]
2024-01-17 Fixes to make board suitable for local manucatruing
    - Track made 0.2 min
    - Pads 0.2 min(CP2102)
    - Another bug fixes...
    [Reader.kicad_pcb, Reader.kicad_sch]
2024-02-10 Bugfixes and improvements
    * Relay was inverted:))
    * Enabled watchdog
    * Logout button support
2024-02-10 Support new type of device: door
2024-02-10 Rev 1.0 of reader added
    [ESP32-WROOM-32.step, G5LE_1A4.step, PKMCS0909E4000-R1_MUR.step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]
2024-03-10 Removed old versions
    [3.stp, CAPC_0603.stp, FSM8JSMA Alcoswitch - detailed.stp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]
2024-07-05 Fixed problem with wrong VBUS connection of USB port
    [PRISMO-reader.kicad_pcb, PRISMO-reader.kicad_sch]
2025-06-03 Bugfix with CP2102 connection (#15)
    * fixed CP2102 peripheral connection
    * renamed leds in order of connection
    [PRISMO-reader.kicad_pcb, PRISMO-reader.kicad_sch]
2025-06-03 Updated gerber files to most recent version
2025-07-29 Create README.md
    3d model files for printing the reader shells for outdoor and indoor use
2025-07-29 3d models for reader shells
    a set of 3d models for printing reader shells for indoor and doutdoor use
    [Reader_internal_for_plasterboard.stl, Reader_internal_plasterboard.f3d, Reader_shell_v3.f3d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]
2025-12-20 Refactoring coding base (#16)
    * - moved relay position on a few mm
    - fixed hostname configuration
    - deleted wifi connection timeout
    - decreased watchdog period
    * - moved relay position on a few mm
    - fixed hostname configuration
    - deleted wifi connection timeout
    - decreased watchdog period
    * - massive code refactor
    - fixed led animation on booting
    - checked and wrapped by try/except all places where use external module and network
    - checked timeouts on network communication
    - added new melody "error" and set use it when we catch an exception on card reading
    * delete ota class (feature not ready)
    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
    [PRISMO-reader.kicad_pcb]
2026-05-15 version name update
    [ESP32-WROOM-32.step, G5LE_1A4.step, PKMCS0909E4000-R1_MUR.step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]
